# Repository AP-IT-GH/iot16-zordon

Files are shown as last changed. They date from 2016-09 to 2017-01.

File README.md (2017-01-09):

# Internet of Things - [Zordon].
## Beschrijving Project

Zordon zal in staat zijn een relais of een transistor aan te sturen doormiddel van stem bediening. Hiermee kunnen we dus bijvoorbeeld stopcontacten en andere dingen aansturen met behulp van een stem. Je smartphone heb je bijna altijd bij je en is hierdoor het ideale apparaat om dingen aan en uit te schakelen in en rond het huis. Dit aan en uitzetten zal gaan via simpele stemcommando's bijvoorbeeld door te zeggen Zordon, doe het slaapkamerlicht aan  en dan zal het licht aangaan in de slaapkamer. De reden waarom we het via een smartphone doen en niet via een Raspberry PI is omdat die een centraal punt in het huis moet inemen en je er dus altijd naartoe moet lopen mocht je iets willen aansturen. Een smartphone is mobieler en hierdoor niet alleen in het huis te gebruiken maar ook onderweg naar huis of waar ook maar internet te vinden is.

Hoe we dit gaan aanpakken als developer en als hardware producent is door ten eerste een Android applicatie maken. De gebruiker logged zich in op de applicatie en verbind via MQTT met de cloud. In de Android applicatie staan al zijn apparaten die hij gekoppeld heeft met het cloud platform. Wanneer hij dan bijvoorbeeld zegt dat hij de lichten aan wil sturen dan wordt zijn stem opgenomen en doorgestuurd naar de Google cloud service daarin wordt de zin die werd gezegd omgevormd naar tekst, die dan zal doorgestuurd worden naar een cloud die het MQTT protocol ondersteund. In de cloud kijken we dan welke module er moet aangestuurd worden. Dit wordt dan doorgestuurd naar de correcte arduino via MQTT, die dan een relais zal schakelen waardoor de lichten zullen aangaan. Wij zullen een PCB maken waarin een WeMos zit samen met een relais, deze complete module zal in een stopcontact passen en aan de andere kant ook een stopcontact hebben zodat het op alle aparaten met een stekker aan te sluiten is.

Dit is ons basis project, dit willen we uitgevoerd krijgen tegen het einde van het semester. Als we tijd over hebben kunnen we nog extra features toevoegen. We denken momenteel aan volgende features. Ons idee is momenteel om het via stopcontacten te doen, we denken er aan om het misschien via fittings van lampen te doen, al denken we wel dat we hier niet voldoende tijd voor zullen hebben. Ook zal de applicatie initieel alleen Nederlands ondersteunen, de bedoeling is om dit uit te breiden naar het engels. Ook willen we een soort talk-back systeem maken, zodat je ook kan vragen wat voor weer het is of wie de sterkste man op aarde is. We willen dit uitbreiden doormiddel van Wolfram Aplha, dit zal betekenen dat deze functie alleen beschikbaar zal zijn in het Engels of anders doormiddel van een vertaal api naar het Nederlands vertaalt zal moeten worden wat problemen kan veroorzaken. 

https://github.com/AP-Elektronica-ICT/iot16-zordon/blob/master/doc/Projectplan.md

## Documentatie
https://github.com/AP-Elektronica-ICT/iot16-zordon/tree/master/doc
## Groepsleden
#####Boyd Franken

#####Kenny Guldentops

#####Gillian Lambrechtss

#####Jeroen Rietveld

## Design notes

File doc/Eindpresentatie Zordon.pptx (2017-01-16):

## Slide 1

Zordon

Jeroen Rietveld
Gillian Lambrechts
Boyd Franken
Kenny Guldentops

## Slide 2

Wat is Zordon

- Mobile home automation
- Spraak
- Besturen van diverse apparaten
- Cloud
- Schaalbaar

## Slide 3

Teamwork is the dreamwork

- Brainstormen over project, hoe pakken we dit het beste aan
- Taken verdeling met behulp van Github Classroom
- Voor module 1 hebben we in 2 teams gewerkt
  - Hardware team: maakt de eerste nodig device dat aangestuurd moet worden
  - Software team: maakt de nodig basic software voor een goede werking van de hardware
- Voor module 2 hebben we allemaal aparte apparaten gemaakt
  - Boyd – Temperatuur
  - Jeroen – Weegschaal en PCB
  - Gillian – Slot
  - Kenny – Slot en deurbel

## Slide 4

Flowchart van zordon

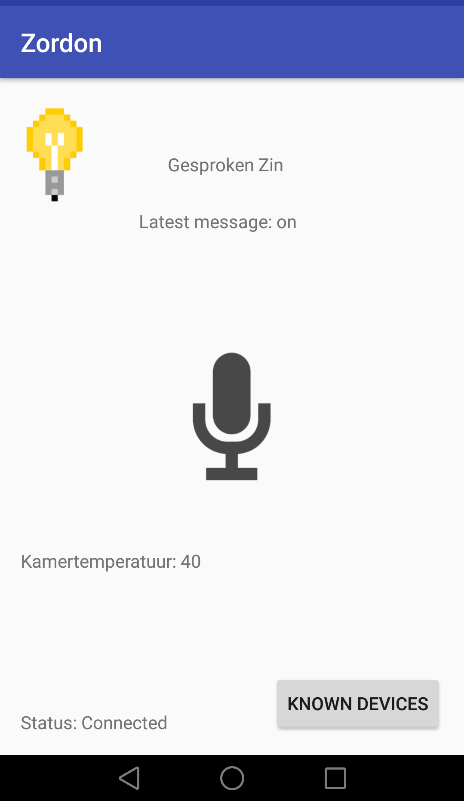
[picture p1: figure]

Cloudmqtt.com

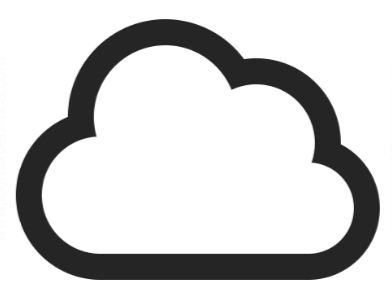
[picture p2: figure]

MQTT

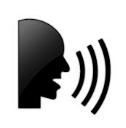
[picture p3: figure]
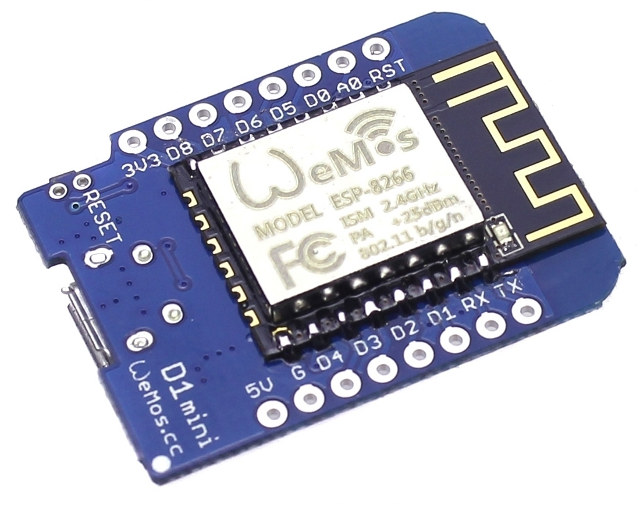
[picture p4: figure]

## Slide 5

Powerplug

- Wemos
- Relais
- 230 naar 5V converter
- Logic converter voor 3,3V signaal naar 5V
- Wordt weergegeven in app als lampje
- Kan apparaten dat op stopcontact werkt aansturen
- Commando’s “Keuken”, “aan”, “uit”

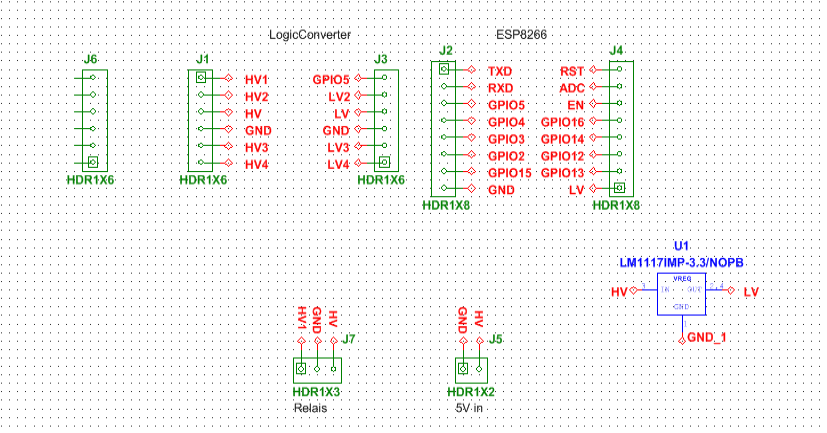
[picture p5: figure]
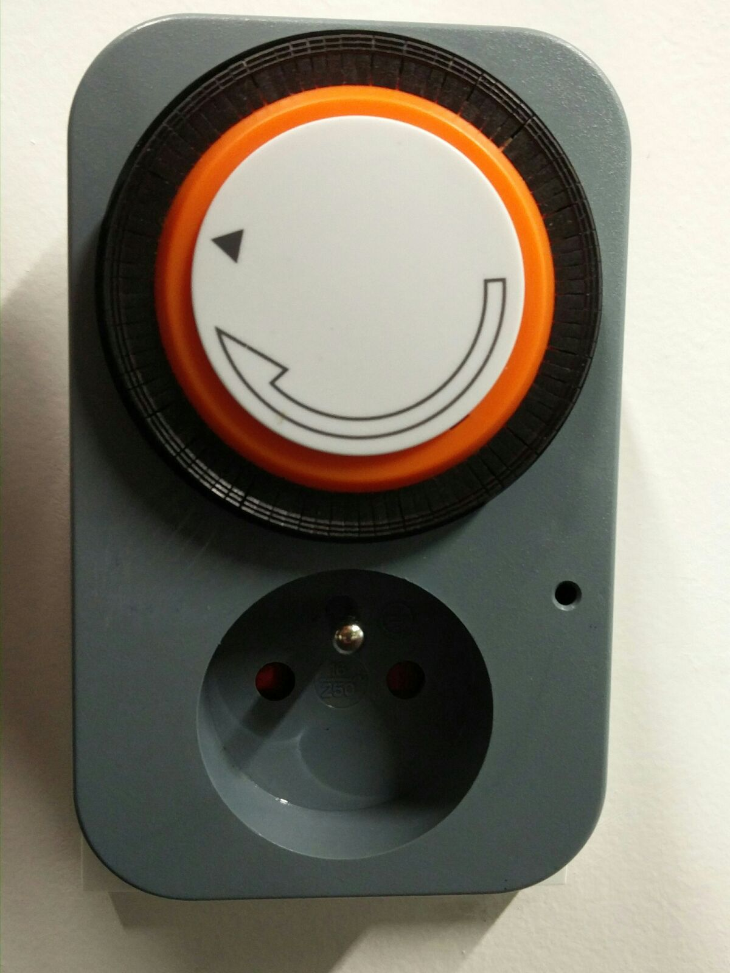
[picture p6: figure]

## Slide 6

Bel/Temperatuur

- NTC sensor in serie met weerstand sensor voor temperatuur meting
- Drukknop met weerstand voor sturen van de bel
- Beiden verbonden met één Wemos
- Word weergegeven en afgespeeld in app

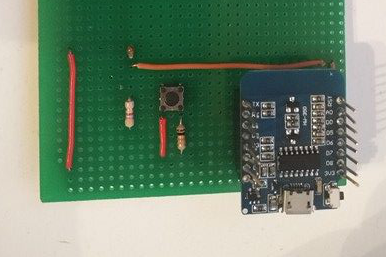
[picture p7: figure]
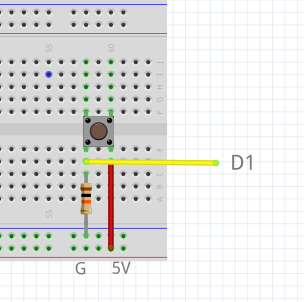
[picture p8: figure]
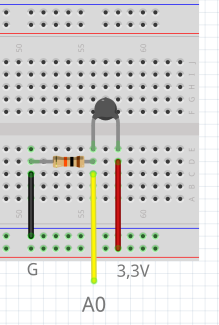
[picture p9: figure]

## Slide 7

Deurslot

- Servo motor stuurt slot aan
- 3D geprint tandwiel, slot en motor houder dat goed in elkaar staat
- Commando’s “Deur”, “Los”, “Vast”

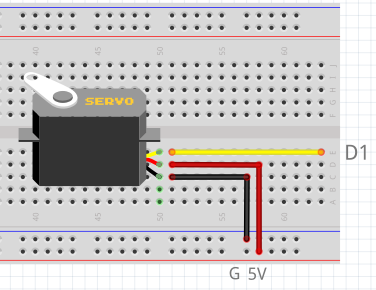
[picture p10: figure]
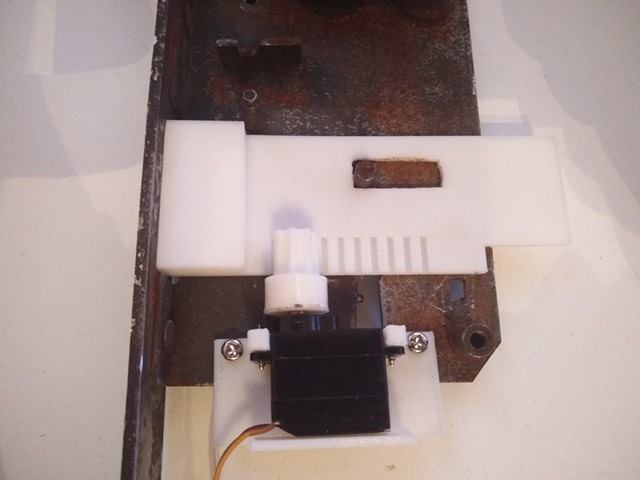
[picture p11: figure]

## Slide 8

Weegschaal

- AD converter
- Druk sensoren in wheatstone bridge opstelling
- Commando’s “calibrate”, “measure”, “tare”, “manual”, “auto”

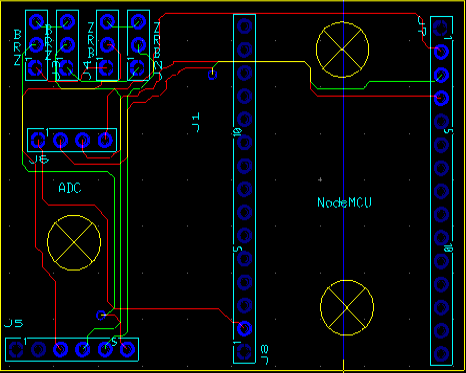
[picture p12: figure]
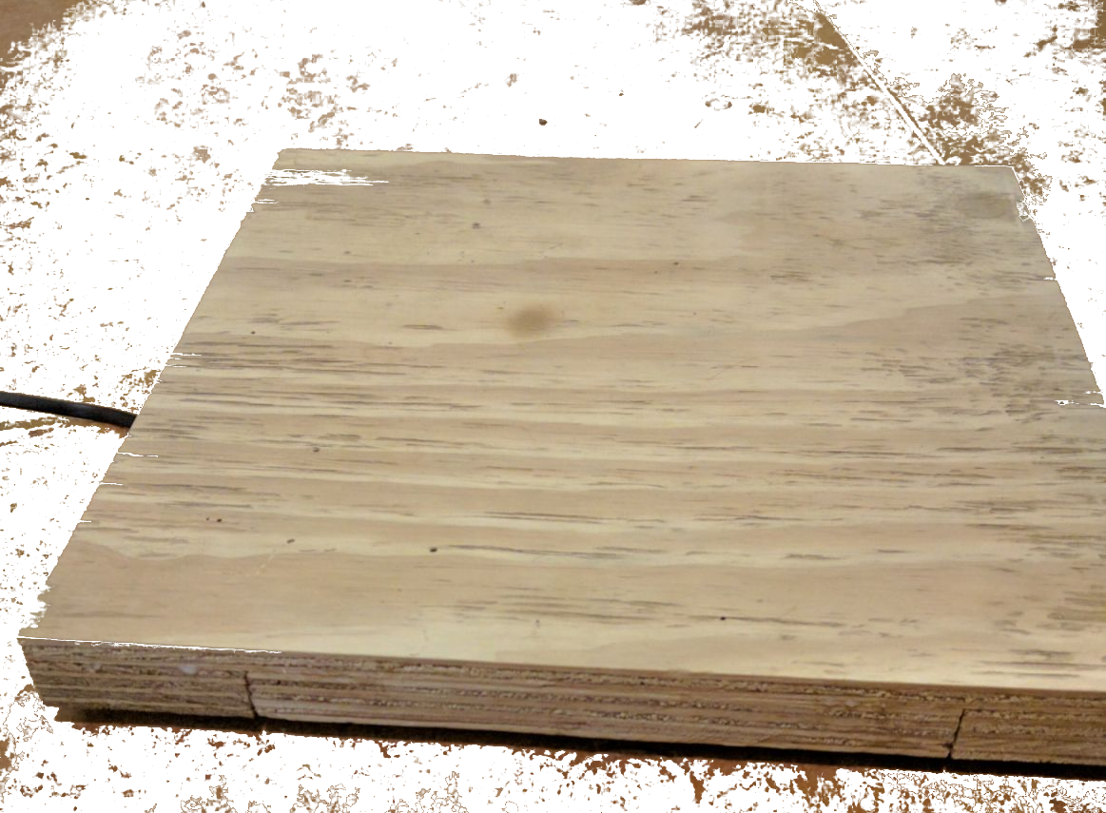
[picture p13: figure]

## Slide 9

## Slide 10

Einde

Bedankt voor uw aandacht

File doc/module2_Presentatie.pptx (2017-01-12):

## Zordon

Jeroen Rietveld
Gillian Lambrechts
Boyd Franken
Kenny Guldentops

## Wat is Zordon

- Mobile home automation
- Spraak
- Besturen van diverse apparaten
- Cloud
- Schaalbaar

## Teamwork is the dreamwork

- Brainstormen over project, hoe pakken we dit het beste aan
- Taken verdeling met behulp van Github Classroom
- Voor module 1 hebben we in 2 teams gewerkt
  - Hardware team: maakt de eerste nodig device dat aangestuurd moet worden
  - Software team: maakt de nodig basic software voor een goede werking van de hardware
- Voor module 2 hebben we allemaal aparte apparaten gemaakt
  - Boyd – Temperatuur
  - Jeroen – Weegschaal en PCB
  - Gillian – Slot
  - Kenny – Slot en deurbel

## Flowchart van zordon


Cloudmqtt.com


MQTT

Afbeeldingsresultaat voor wemos d1 mini png

## Powerplug

- Wemos
- Relais
- 230 naar 5V converter
- Wordt weergegeven in app als lampje
- Kan apparaten dat op stopcontact werkt aansturen
- Commando’s “Keuken”, “aan”, “uit”

## Bel/Temperatuur

- NTC sensor in serie met weerstand sensor voor temperatuur meting
- Drukknop met weerstand voor sturen van de bel
- Beiden verbonden met één Wemos
- Word weergegeven en afgespeeld in app


## Deurslot

- Servo motor stuurt slot aan
- 3D geprint tandwiel, slot en motor houder dat goed in elkaar staat
- Commando’s “Deur”, “Los”, “Vast”


## Weegschaal

- PCB design

## Conclusie

- Volledig werkende app
- Volledig werkende hardware
- Werkend via de cloud
- Schaalbaar, makkelijk om nieuwe hardware toe te voegen

## Einde

Bedankt voor uw aandacht

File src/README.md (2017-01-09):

# Internet of Things - [Zordon] 
Bron bestanden voor het project van het vak Internet of Things.

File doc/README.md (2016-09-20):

# Internet of Things - [Zordon]
Documentatie voor het project voor het vak Internet of Things.

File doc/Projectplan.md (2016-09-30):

# Projectplan

## **Team:** 

Zordon

## **Project keuze:** 

EDI

## **Project beschrijving:**

Wij gaan een applicatie dat een relais zal aansturen door middel van voice control. Hiermee kunnen we dus bijvoorbeeld stopcontacten en andere dingen aansturen met behulp van je stem. Hoe we dit gaan tewerk stellen doen we op volgende manier. We hebben een gebruiker, die een smartphone heeft. Je smartphone heb je altijd in de buurt of toch meestal. Die wilt bijvoorbeeld dat er een lichtje in de slaapkamer aangaat wanneer hij wakker wordt. Wat hij dan doet is hij zegt “Zordon, doe het slaapkamer licht aan” en dan zal het licht aangaan van de slaapkamer. De reden waarom we het via een smartphone doen en niet via een Raspberry PI is omdat die een centraal punt in het huis en je dus altijd naar daar moet lopen wil je iets aansturen. Een smartphone is mobieler.

Hoe we dit gaan aanpakken als developer en als hardware producent is door ten eerste een android applicatie maken. De gebruiker logged zich in op de applicatie en verbind zo met de cloud. In de cloud staan al zijn apparaten die hij gekoppeld heeft in het huis. Wanneer hij dan bijvoorbeeld zegt dat hij de lichten aan wilt sturen dan wordt zijn stem opgenomen en doorgestuurd naar de Google cloud service daarin wordt de zin die werd gezegd omgevormd naar tekst, die dan zal doorgestuurd worden naar een cloud die het MQTT protocol ondersteund. In de cloud kijken we dan welke module er moet aangestuurd worden. Dit wordt dan doorgestuurd naar de correcte arduino over wifi, die dan een relais zal schakelen waardoor de lichten zullen aangaan. Wij zullen een PCB maken waarin een Arduino zit samen met een wifi relais module die in het stopcontact past.

Dit is ons basis project, dit willen we uitgevoerd krijgen tegen het einde van het jaar. Als we tijd over hebben kunnen we nog extra features toevoegen. We denken momenteel aan volgende features. Ons idee is momenteel om het via stopcontacten te doen, we denken er aan om het misschien via lichtschakelaars te doen, al denken we wel dat we hier niet voldoende tijd voor zullen hebben. Momenteel is onze applicatie ook één enkele taal dat wordt ondersteund, de bedoeling is om dit uit te breiden naar meerderen. Ook willen we een soort talk-back systeem maken, zodat als je zegt dat de lichten aan moet, dat het systeem dan terug zegt dat de lichten aan zijn, of dat het niet is gelukt. Momenteel is dit ook allemaal voor geprogrammeerde zinnen, we willen dit uit breiden naar dat de gebruiker kan zeggen van dit is de zin die ik wil dat dit aanstuurt, en dit is de zin die ik terug wil krijgen. 

## **Functionele analyse:**

#### Analyse
Wij gaan gebruik maken van volgende technologieën. Ten eerste gaan we een Android applicatie maken, dus maken we gebruik van Android. In deze applicatie gaan we gebruik maken van Cloud services, MQTT protocol en voor de Android applicatie gaan we gebruik maken van Android Cloud Speech API. Verder maken we gebruik van Wifi. Voor hardware maken we gebruik van een Wifi Relais Module (ESP8266). Om dan deze te programmeren maken we gebruik van een Arduino Nano. 

---

#### High level blokdiagram



---

#### Flowchart

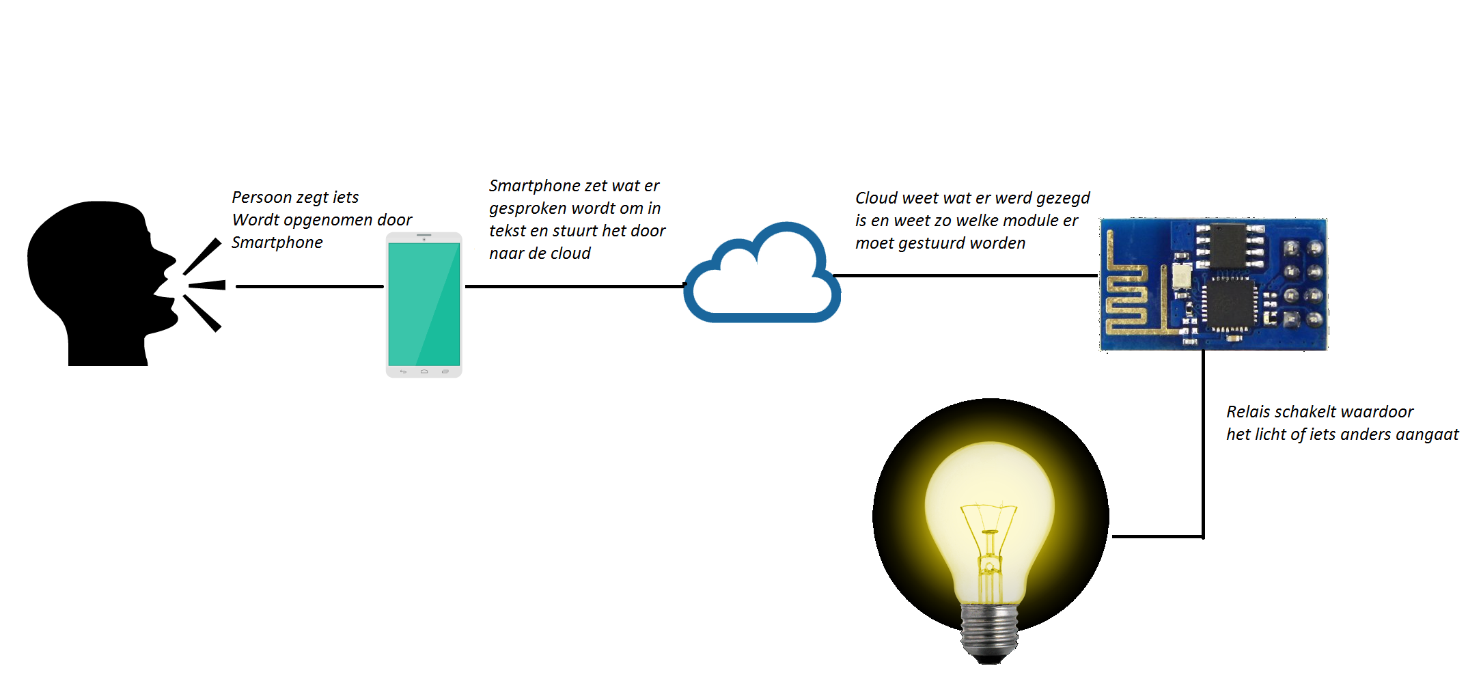
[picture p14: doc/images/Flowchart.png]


---

#### Backlog

**Als gebruiker wil ik via spraak apparaten kunnen activeren (Aanzetten)**  
*Het activeren van de apparaten zal via MQTT naar de cloud gaan, de spraak detectie wordt gemaakt met behulp van Google Cloud Speech API*  
**Als gebruiker wil ik via spraak apparaten kunnen deactiveren (Uitzetten)**  
*Het deactiveren van de apparaten zal via MQTT naar de cloud gaan, de spraak detectie wordt gemaakt met behulp van Google Cloud Speech API*  
**Als gebruiker wil ik apparaten kunnen toevoegen**  
*Als gebruiker wil ik apparaten kunnen toevoegen*  
**Als gebruiker wil ik kunnen zien welke apparaten aan en uit zijn**  
*Een cloud platform instellen die MQTT apparaten kan beheren*  
**Als gebruiker wil ik kunnen zien welke apparaten er van mij gekend zijn**  
*Een korte lijst in de android app die de status van de apparaten in de cloud uitleest*  
**Als gebruiker wil ik spraak confirmatie van mijn spraak opdracht**  
*De ESP8266 zal via MQTT een confirmatie bericht sturen naar de cloud, die dan aan de Android app zal laten weten of het apparaat aanstaat via spraak*  
**Als gebruiker wil ik kunnen inloggen zodat ik kan zien welke apparaten er beschikbaar zijn en welke ik kan besturen**  
*Er zal een database zijn met beschikbare gebruikers zodat zij alleen toegang hebben tot hun beschikbare apparaten*  
**Als gebruiker wil ik via touch input mijn apparaten manueel kunnen besturen**  
*Een lijst die al de beschikbare apparaten weergeeft en ze hiermee ook kunt besturen*  

---
## Planning Sprint 1 & 2
https://github.com/AP-Elektronica-ICT/iot16-zordon/projects/2

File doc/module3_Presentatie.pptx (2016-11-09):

## Project Zordon

Boyd Franken
Kenny Guldentops
Gillian Lambrechts
Jeroen Rietveld
3EA2

## Inhoudsopgave

- Zordon introductie
- Zordon Software
- Zordon Hardware
- Toekomstplannen voor Zordon
- Zordon Afsluiting

## Zordon introductie

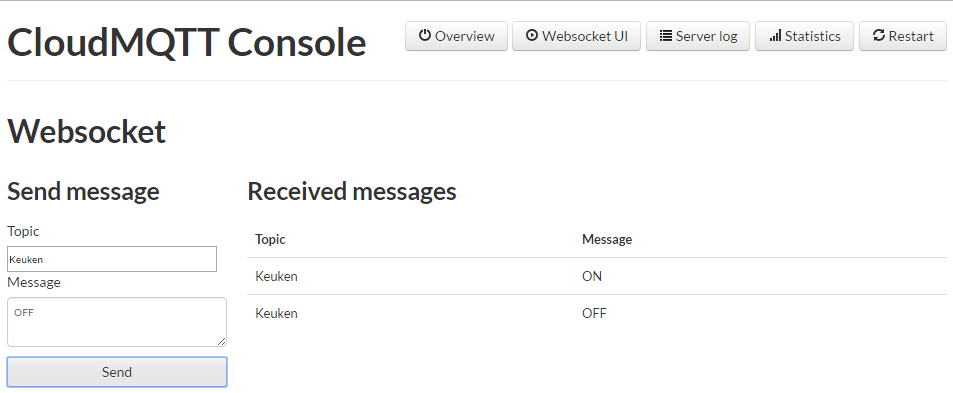
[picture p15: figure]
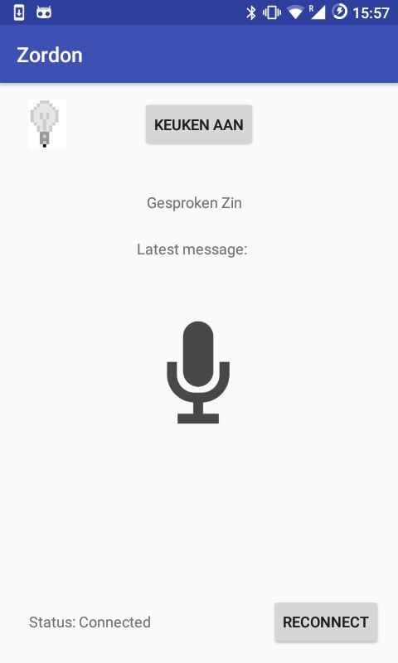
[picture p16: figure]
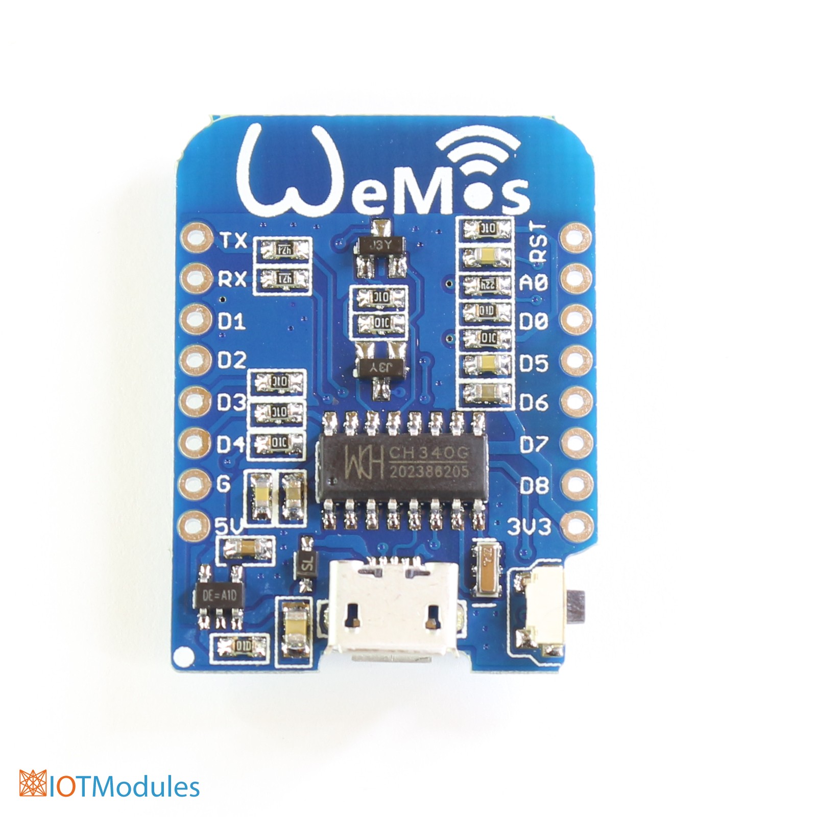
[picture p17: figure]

## Zordon Hardware

## Zordon Software

- Android app
- Speech to text
- PAHO Android MQTT

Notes: Speech to text gebeurt met de google api voor android studio. Het neemt op wat je inspreekt en streamt dat naar de google servers, daar wordt de gesproken zin geconverteerd naar een string die dan in de activity wordt getoond.
De stem herkenning maakt gebruik van de systeemtaal van de smartphone, dus als je smartphone in het engels staat zal die bijvoorbeeld nederlandse woordjes verstaan
Dit was vrij simpel om toe te passen, in android studio

Daarnaast maken we ook nog gebruik van MQTT.
We gebruiken de PAHO bibliotheek om zo gebruik te maken in android studio van MQTT. Er zijn ook nog andere bibliotheken voor MQTT toe te passen in android studio maar deze leek ons het beste.
Wat we nu allemaal doen met deze bibliotheek is ten eerste een connectie maken met onze Cloud MQTT. Dit gebeurt allemaal in de achtergrond dus je moet je nooit terug opnieuw aanmelden. Ook als je WIFI even wegvalt hebben we ervoor gezorgd dat je terug reconnect wanneer je verbinding terug is. We laten dit op het scherm zien, de status of je connected bent of niet. Dit kan je hier zien: (Laat korte demo zien).

Daarnaast moeten we natuurlijk ook messages kunnen sturen van de android app naar de de cloud. En de message die we willen sturen is natuurlijk hetgeen wat de gebruiker commandeert. We gaan dus de google speech to tekst api laten samenwerken met MQTT. Als gebruiker bijvoorbeeld zegt dat de keuken lichten aan moeten, dan filteren we de woorden ‘Keuken’ en ‘Aan’ uit deze zin, we gebruiken dus keywords, omdat dit minder kans heeft op falen dan een hele zin. Deze 2 keywords worden dan verstuurd naar de cloud, de plaats onder topic, de state onder message (Dus topic: keuken, message ‘aan’). Ook hebben we ervoor gezorgd dat als er een foute zin wordt gezegd, dat de message dan niet word gestuurd, om zo overlast op de cloud tegentehouden.

We hebben ook nog subscribe toegevoegd aan de app. Dit is meer voor confirmatie, zodat we wel degelijk zeker zijn dat de lichten op die plaats aan is.

## Toekomstplannen voor Zordon

## Zordon Afsluiting

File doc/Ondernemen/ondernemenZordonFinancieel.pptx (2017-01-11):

## Zordon Financieel

Boyd Franken
Kenny guldentops
Gillian lambrechts
Jeroen rietveld

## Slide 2

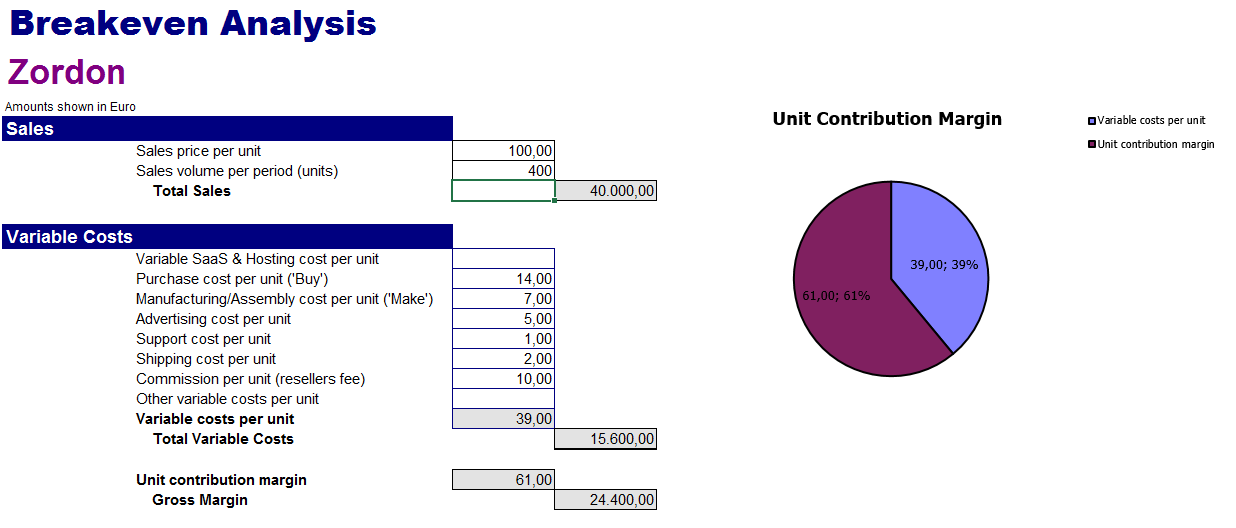
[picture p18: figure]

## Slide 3

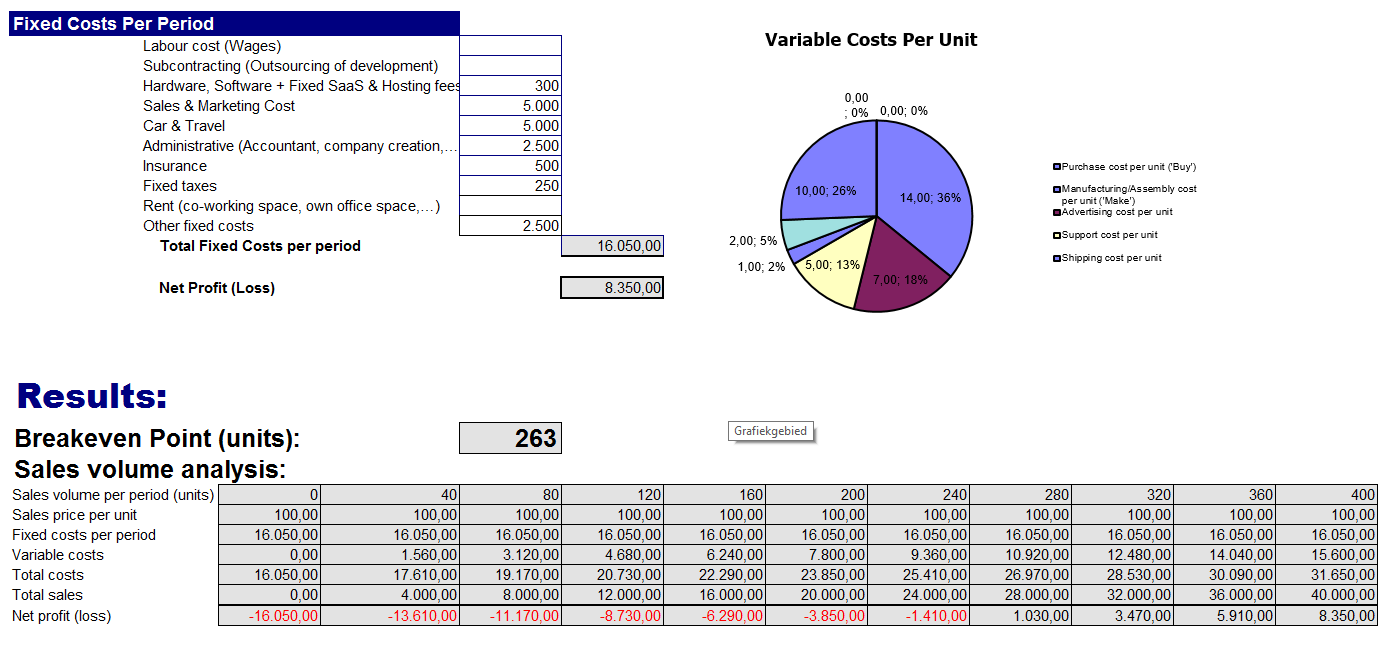
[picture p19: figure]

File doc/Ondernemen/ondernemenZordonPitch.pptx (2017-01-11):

## Zordon

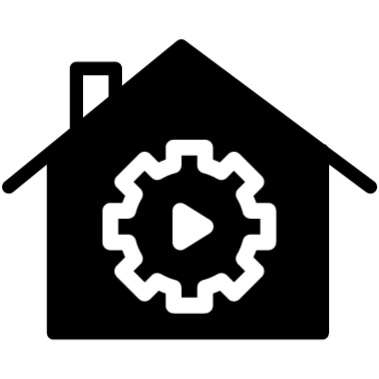
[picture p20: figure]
No automatic alt text available.

Automating homes one by one

boYD Franken
Kenny Guldentops
Gillian lambrechts
Jeroen rietveld

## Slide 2

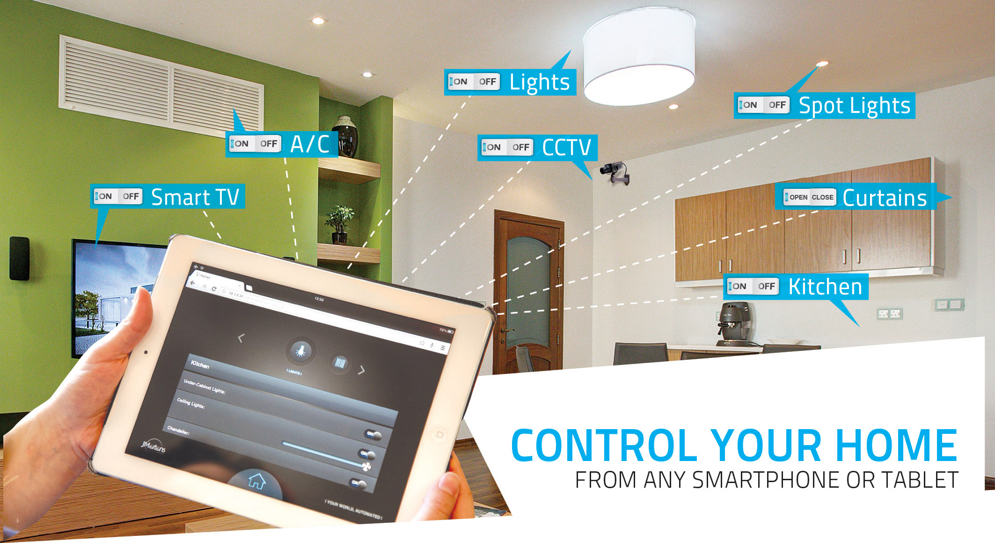
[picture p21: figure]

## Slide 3

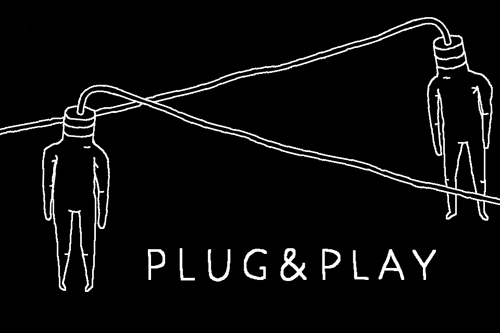
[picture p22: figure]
Image result for plug & play

## Modulair

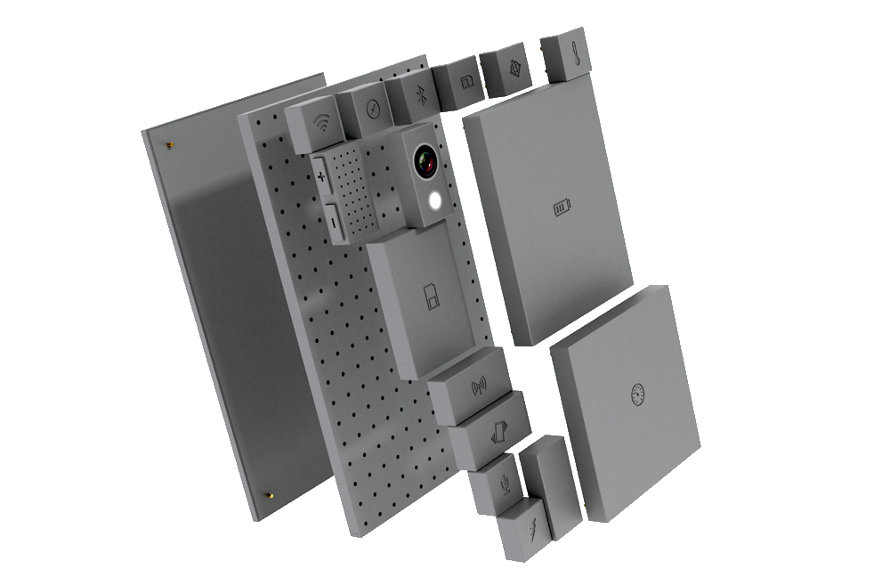
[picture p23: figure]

## Scaleability

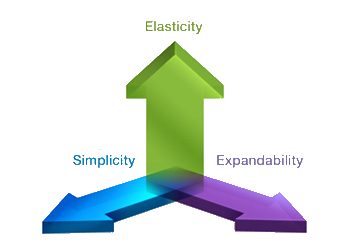
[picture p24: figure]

## Cloud


## Mobility

Related image

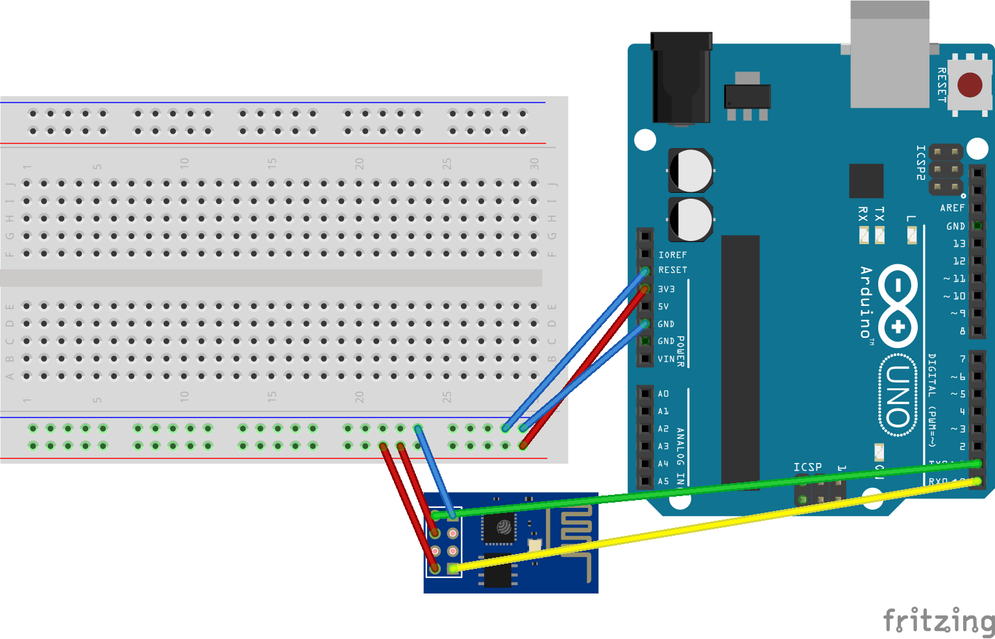
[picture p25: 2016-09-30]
doc/images/WifiModuleConfiguration.png

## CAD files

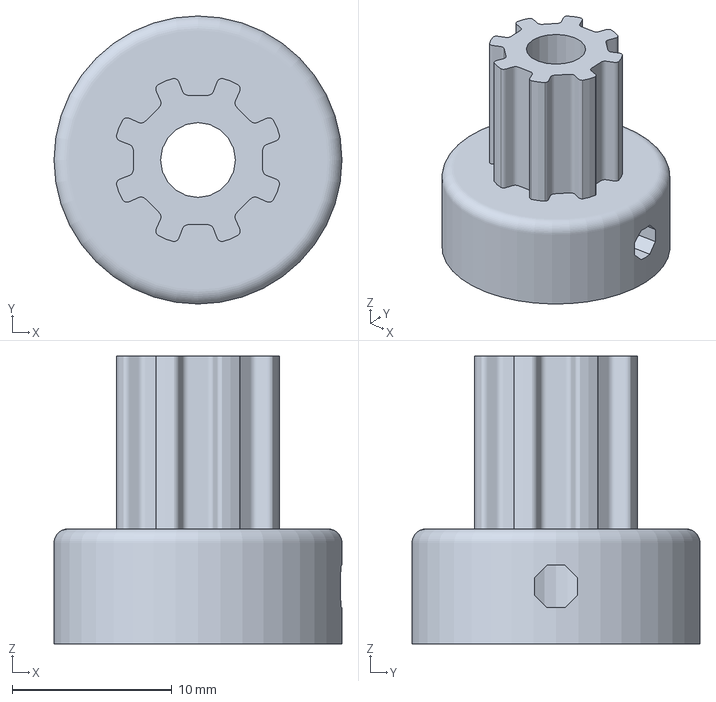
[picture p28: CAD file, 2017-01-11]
src/3d prints/gear.3mf
18.0 x 18.0 x 18.0 mm

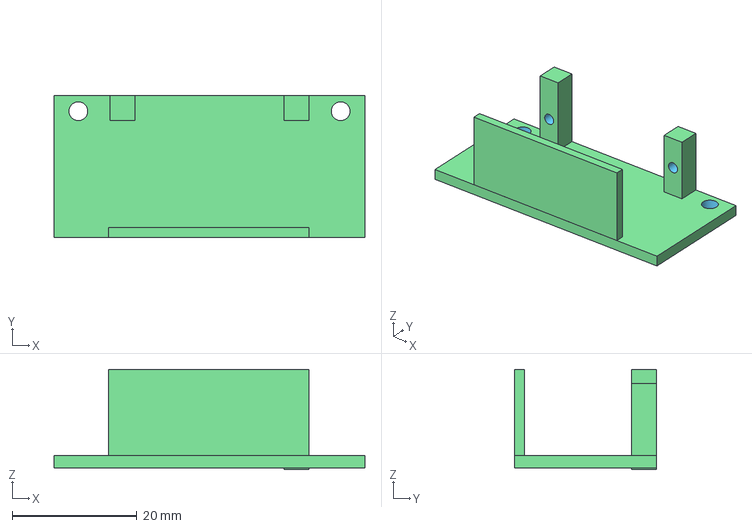
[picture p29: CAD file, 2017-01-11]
src/3d prints/test houder.3mf
49.8 x 22.7 x 16.0 mm

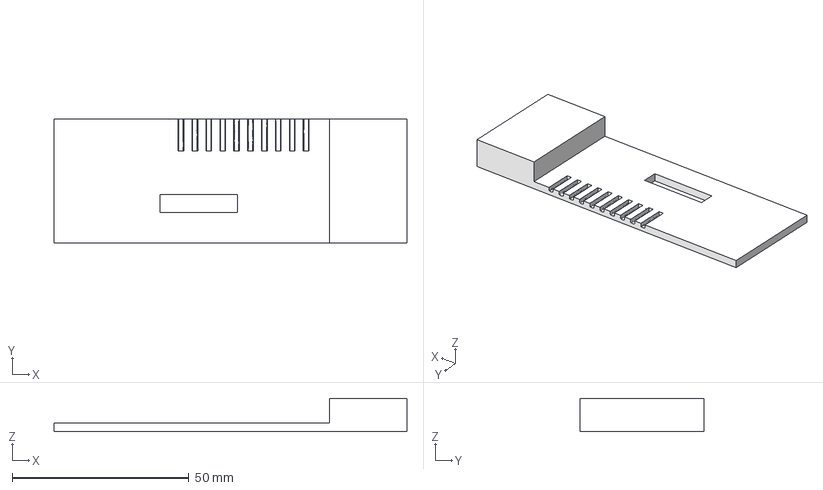
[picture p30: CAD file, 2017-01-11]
src/3d prints/slot.3mf
100.0 x 35.0 x 9.40 mm

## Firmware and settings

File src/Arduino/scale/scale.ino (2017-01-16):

#include <ESP8266WiFi.h>
#include <PubSubClient.h>
#include "HX711.h"

HX711 scale;
float weight;


const char *ssid =  "Connectify-BOYD";   // cannot be longer than 32 characters!
const char *pass =  "aphogeschool";

const char *mqtt_server = "m21.cloudmqtt.com";
const int mqtt_port = 12452;
const char *mqtt_user = "xnkcayag";
const char *mqtt_pass = "DtCGtuL2kVfk";
const char *mqtt_client_name = "scale"; // Client connections cant have the same connection name

String thisDevice = "scale"; // Subscribe to this topic and publish with this as context
bool manual;

WiFiClient wclient;
PubSubClient client(wclient, mqtt_server, mqtt_port);

#define BUFFER_SIZE 100

void setup() {
  scale.begin(D2, D3);

  scale.set_scale(-2081995.00/105);                      // this value is obtained by calibrating the scale with known weights; see the README for details
 

  pinMode(D1, OUTPUT);
  // Setup console
  Serial.begin(115200);
  delay(10);
  Serial.println();
  Serial.println();

}

void loop() {
  if (WiFi.status() != WL_CONNECTED) {
    Serial.print("Connecting to ");
    Serial.print(ssid);
    Serial.println("...");
    WiFi.begin(ssid, pass);

    if (WiFi.waitForConnectResult() != WL_CONNECTED)
      return;
    Serial.println("WiFi connected");
  }

  if (WiFi.status() == WL_CONNECTED) {
    if (!client.connected()) {
 //     Serial.println("Connecting to MQTT server");
      if (client.connect(MQTT::Connect("arduino")
                         .set_auth(mqtt_user, mqtt_pass))) {
    //    Serial.println("Connected to MQTT server");
        client.subscribe(thisDevice);
      } else {
        Serial.println("Could not connect to MQTT server");   
      }
    }

    if (client.connected())
      client.loop();
  }
  if (!manual) {
weight = scale.get_units(1);
  if (weight > 40) {
    Send("heavy");
    float testWeight = scale.get_units(30);
    while (weight > testWeight -0.01 && weight < testWeight +0.01){
      
      Serial.print("Please stand still ");
      Serial.println(weight);
      Serial.print("  ");
      Serial.println( testWeight); 
      weight =  testWeight;
       float testWeight = scale.get_units(1);
    }
    weight = scale.get_units(10);
    char buffer[50];
      String sendWeight = dtostrf(weight,2,2,buffer);
      sendWeight.replace(".",",");
    Send("dit weegt: " + sendWeight + "Kilogram");
    int i = 60000;
   float  checkWeight = weight;
    while (weight > checkWeight - checkWeight/2) {
            Serial.print(weight);
      Serial.print("  ");
      Serial.println(checkWeight);
      weight = scale.get_units(1);
      i++;
      if (i > 60000) {
      Send("get off");
      i=0;
      }
      
    }
     Send("light");
    delay(500);
    scale.tare();
   
  }

  }


  Recieve();
}

void Send(String data){

    Serial.print("published data");
   client.publish("Android/" + thisDevice, data );

  }

  void Recieve(){

                      
      //  Serial.println("Recieving");
        client.set_callback(callback);
        
    
      }
    
      
  
  void callback(const MQTT::Publish& pub) {
    String message = (pub.payload_string());
    message.trim();
  //  Send(message);
    Serial.println(message);

    if (message == "measure") {

      weight = scale.get_units(1);
      char buffer[50];
      String sendWeight = dtostrf(weight,2,2,buffer);

      Send(sendWeight);
      
    }
    
    else if (message == "calibrate") {
      delay(5000);
         Send("taring");
      scale.set_scale();
      delay(1000);
      scale.tare();  
      Send("get off and wait");

      delay(15000);

      weight = -scale.get_units(1);
     
      scale.set_scale(weight/105);  
       scale.tare();  
             char buffer[50];
      String sendWeight = dtostrf(weight,2,2,buffer);

      Send("recalibrated at " + sendWeight );
      
      
    }
       else if (message == "tare") {
        scale.tare();  
       }
        else if (message == "manual") {
        manual = true;
        Send("manual");
       }
        else if (message == "auto") {
        manual = false;
        Send("auto");
       }

//Change the name of the device
    else if(message.indexOf("cN") >= 0) {
      client.unsubscribe(thisDevice);
      thisDevice = message;
      thisDevice.remove(0, 2);
      Serial.print("changed name");
      client.subscribe(thisDevice);
    }
    
}

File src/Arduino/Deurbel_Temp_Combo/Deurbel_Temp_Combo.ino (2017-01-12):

int switchPin = D1;
boolean lastButton = LOW;
boolean currentButton = LOW;

#include <ESP8266WiFi.h>
#include <PubSubClient.h>
#include <Thermistor.h>

const char *ssid =  "Connectify-BOYD";   // cannot be longer than 32 characters!
const char *pass =  "aphogeschool";

const char *mqtt_server = "m21.cloudmqtt.com";
const int mqtt_port = 12452;
const char *mqtt_user = "xnkcayag";
const char *mqtt_pass = "DtCGtuL2kVfk";
const char *mqtt_client_name = "Weemo_deurbel"; // Client connections cant have the same connection name

String Deurbel = "Android/Deurbel"; // Subscribe to this topic and publish with this as context
String TemperatuurSensor = "Android/kamertemperatuur"; // Subscribe to this topic and publish with this as context
String verwarming = "Android/verwarming";

long previousMillis = 0;    
long interval = 10000; 

WiFiClient wclient;
PubSubClient client(wclient, mqtt_server, mqtt_port);

#define BUFFER_SIZE 100

Thermistor temp(0);

void setup()
{
  pinMode(switchPin, INPUT);
  pinMode(A0, OUTPUT);
  pinMode(D2, OUTPUT);
  Serial.begin(9600);
}

boolean debounce(boolean last)
{
  boolean current = digitalRead(switchPin);
  if (last != current)
  {
     delay(5);
    current = digitalRead(switchPin);
  }
  return current;
}

void loop(){
    unsigned long currentMillis = millis();
    int temperature = temp.getTemp();
    if (WiFi.status() != WL_CONNECTED) {
    Serial.print("Connecting to ");
    Serial.print(ssid);
    Serial.println("...");
    WiFi.begin(ssid, pass);

    if (WiFi.waitForConnectResult() != WL_CONNECTED)
      return;
    Serial.println("WiFi connected");
  }

  if (WiFi.status() == WL_CONNECTED) {
    if (!client.connected()) {
      Serial.println("Connecting to MQTT server");
      if (client.connect(MQTT::Connect(mqtt_client_name)
                         .set_auth(mqtt_user, mqtt_pass))) {
        Serial.println("Connected to MQTT server");
        client.subscribe(Deurbel);
        Serial.println("Subscribed to: " + Deurbel);
        client.subscribe(TemperatuurSensor);
        Serial.println("Subscribed to: " + TemperatuurSensor);
        client.subscribe(verwarming);
        Serial.println("Subscribed to: " + verwarming);
      } else {
        Serial.println("Could not connect to MQTT server");   
      }
    }
    
    if (client.connected()){
    currentButton = debounce(lastButton);
    
    if(currentMillis - previousMillis > interval) {
      previousMillis = currentMillis;
      SendTemp(temperature);
    }
    
    if (lastButton == LOW && currentButton == HIGH){
      Serial.println("Button pressed");
      Send("bel");
    }
    lastButton = currentButton;
    client.loop();  
    }
  }
}
  void Send(String data){
     Serial.println("published data");
     client.publish(Deurbel, String(data) );
  }
  
  void SendTemp(int data){
   Serial.println("Sending data");
   client.publish(TemperatuurSensor, String(data) );
  }
  void Receive(){       
      Serial.println("Receiving");
      client.set_callback(callback);       
  }
 
  void callback(const MQTT::Publish& pub) {

           
}

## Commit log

2016-09-30 Added photo of the right wiring of arduino and the ESP8266
2016-10-14 Added Arduino MQTT sketch
2016-10-14 Feature toegevoegd dat hetgeen wat je zegt wordt verzonden naar de MQTT cloud. Alsook een reconnect button
2016-10-15 Added MQTT response to arduino code
2016-10-21 filtering van de gesproken woorden voor minimun mqtt data
2016-10-21 Test subscriben in de manual send button
2016-10-21 De pinnetjes volgorde van de header.
2016-11-09 Added change name feature to arduino code
2016-11-09 Fixed name change feature
    [MQTTArduino.ino]
2016-11-09 Removed reconnect button, want gebeurt nu automatisch, alsook label van message button aangepast
2016-11-28 Working temperature sensor publishing data to MQTT. Also fixed small spelling mistake in MQQTArduino.
    [TemperatureArduino.ino]
2016-11-28 If the temperature goes above 24, the kitchen goes on.
2016-12-05 Added pubsub library to Arduino folder
2016-12-07 Arduino code voor via mqtt de deurbel aan te sturen
2016-12-07 Android code aangepast voor meerdere devices te ondersteunen. De deurbel maakt een geluidje via de app wanneer er op de button wordt geduwt.
2016-12-07 Made client ID's unique so more than one (arduino) connection can be set up to the MQTT server.
2017-01-09 Arduino code for doorlock
2017-01-11 finished pitch presentation
2017-01-11 Duerslot is toegevoegd aan de commands die je kan geven
2017-01-11 Servo op juist topic ge subscribed en andere keywords dan on en off gebruikt
2017-01-11 android app servo gedeelte naar juiste keywords gezet
2017-01-11 Added First half of lean vanvas to pitch presentation
2017-01-11 Added First half of lean canvas to pitch presentation
2017-01-11 3d prints map toegevoegd en presentatie marketing voor ondernemen
    [gear.3mf, slot.3mf, test houder.3mf]
2017-01-12 Deurbel + temperatuur samen werkende op één wemos
2017-01-16 Added scale and powerplug schematic to presentation
